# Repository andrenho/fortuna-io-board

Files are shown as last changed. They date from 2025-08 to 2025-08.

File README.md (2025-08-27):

# Fortuna IO board

**Fortuna I/O board** is a board that provides multiple I/O ports, and can be used to build a custom computer.

Board
VGA

The board main component is a [Raspberry Pi Pico 2 W](https://www.raspberrypi.com/products/raspberry-pi-pico-2/), which
has 2 processor cores. The 2nd core is used for managing the board I/O, leaving the 1st board available for whatever
the user decides to implement.

The board and accompanying firmware library provides:

 - 1 Raspberry Pi Pico 2 W core available for user implementation (3.8 MB flash and 350 kB RAM free)
 - USB power with on/off switch
 - VGA output at 640x480, 640x240 or 320x240 in 16 colors
 - special VGA mode at 320x240 with a background framebuffer + sprites (mode 4)
 - VGA text with 4 different fonts
 - support for USB keyboard
 - SD Card storage (using the libraries and [no-OS-FatFS-SD-SDIO-SPI-RPi-Pico](https://github.com/carlk3/no-OS-FatFS-SD-SDIO-SPI-RPi-Pico) and [FatFs](https://elm-chan.org/fsw/ff/))
 - Real Time (calendar) clock with long term storage, battery operated (CR2032)
 - UART interface (can be used with a FTDI cable)
 - audio output via headphone jack
 - user panel composed of two leds, one pushbutton and 2x microswitch
 - an external SPI interface (via a 5x2 pin IDC connector), allowing the board to be controller externally
 - Wi-Fi and Bluetooth via Pico Pi 2 W

## Schematic

Schematic

Possible variations:
 * Any of these modules, except for the Pico Pi 2 and the Power, are optional.
 * A Pico Pi (not W) can be used instead, if wireless is not needed.

[Download PDF](schematic/pi-pico-vga.pdf)

## Using it in a project

Look at `firmware/io-board/CMakeLists.txt` and `firmware/io-board/demo.c` for an example on how to import and use the library.

## Building the demo

To build the demo:

```shell
mkdir -p firmware/io-board/build
cd firmware/io-board/build
cmake -DPICO_SDK_PATH=~/pico-sdk -DPICOTOOL_FETCH_FROM_GIT_PATH=~/picotool -DPICO_BOARD=pico2 ..   # replace with your directories
make
```

# Emulator

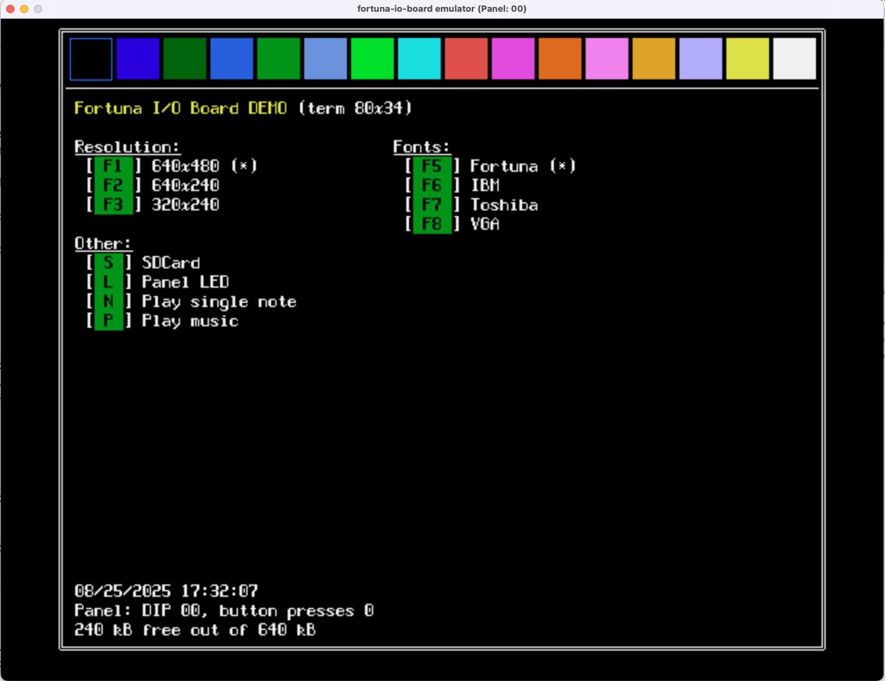
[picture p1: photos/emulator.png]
Emulator


An emulator can be used to test the implementation without having to upload it to the board. To build the emulator:

```shell
mkdir -p emulator/build
cd emulator/build
cmake ..
make
```

The same code that is uploaded to the board can also be used to compile the emulator. Look at `emulator/io-board/demo.c`,
which is just a link to the firmware implementation.

To create a disk image to use in the emulator, use the script `/tools/sdcard/create_image.sh`. To manage the disk image
(copy files to it, etc), the disk image needs to be mounted. In Linux, do 
`mount -o loop MY_IMAGE MOUNT_POINT`; in Mac, do `hdiutil attach MY_IMAGE` and access it through Finder.

(Macs needs to have `dosfstools` installed to use the `create_image.sh` script)

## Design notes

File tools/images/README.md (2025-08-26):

`imagegen.py` will generate an image that can be loaded on the Fortuna I/O Board. To create an image, follow this
procedure.

1. Create the image using the `fortuna.pal` palette file (recommended application: Grafx2)
2. Save image as PNG
3. Call `imagegen.py` to convert the PNG image into a Fortuna image

The image format is as this:

F0 34 -- magic number
01    -- image version (determines also compression type)
xx    -- transparent color (or FF for no transparency)
xx xx -- image width, in pixels
xx xx -- image height, in pixels
..... -- the image pixels (2 pixels per byte)

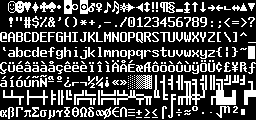
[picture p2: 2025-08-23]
tools/fonts/toshiba.png

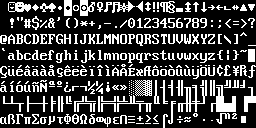
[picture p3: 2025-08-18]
tools/fonts/vga.png

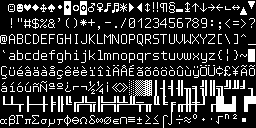
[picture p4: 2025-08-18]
tools/fonts/ibm.png

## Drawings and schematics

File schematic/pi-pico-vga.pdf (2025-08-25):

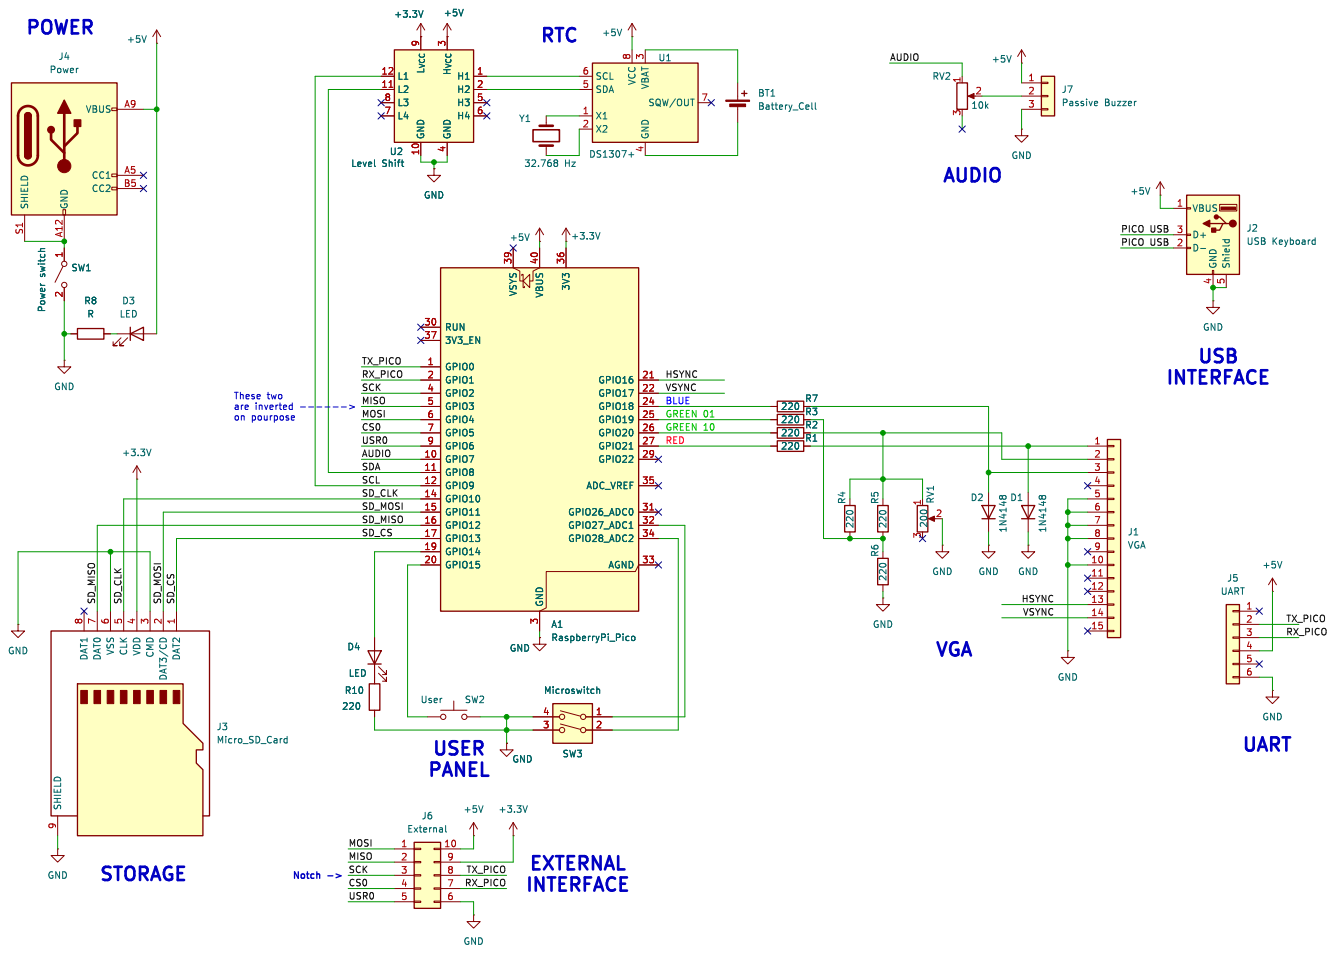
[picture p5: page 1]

4 SQW/OUT 7 U1 DS1307+ GND GND GND GND

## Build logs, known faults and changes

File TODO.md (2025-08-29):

## Version 2.0 - concurrent C version and emulator

- [x] Base (as library)
  - [x] Example implementation 
- [x] VGA framebuffer
  - [x] Framebuffer primitives
- [x] Framebuffer primitives and text
  - [x] Text tools
- [x] Keyboard / mouse / joystick
  - [x] Mouse pointer
- [x] Terminal
  - [x] Location in screen
  - [x] Cursor
  - [x] Colors
  - [x] Other fonts
- [x] Write program
  - [x] Translate HID
- [x] Change resolution
- [x] Memory available
- [x] Bug: font seems to be using RAM
- [x] SD card
- [x] Front panel
- [x] Real-time clock (get/set)
- [x] Audio
  - [x] Fix audio in board
- [x] Documentation

## Version 2.1

- [x] VGA
  - [x] Draw images
    - [x] Create palette and converter
    - [x] Transparency
- [x] Terminal
  - [x] Alternate character set
- [x] Emulator
  - [x] SDCard image file
- [x] Demo program: set clock
- [x] Dumb terminal mode with front panel settings
  - [x] Make it work on the emulator
  - [x] Single array for keys
  - [x] Add special keys
  - [ ] Edit UART configuration, change font, etc (write configuration on startup)
  - [ ] Respond with columns/lines size (and terminal type?)
  - [ ] Make terminal faster by caching fonts
  - [ ] Bell
  - [ ] Make advanced stuff work
    - [ ] vim
    - [ ] mc
    - [ ] nethack
  - [ ] Terminal connection not working very well on linux
- [ ] Update README.md, documentation

## Version 2.2

- [ ] Design communication language
- [ ] External connections
  - [ ] SPI
  - [ ] 4-pin
  - [ ] emulator

## Version 2.3

- [ ] Sprites
- [ ] Improve audio system
- [ ] Compressed images
- [ ] Merge master

## Version 2.4
- [ ] Create WASM version, auto-generate WASM page

--------------------------------------------

## Version 0.1

- [x] VGA simple framebuffer (640x480)
  - [x] Remove excess code
  - [x] Draw single pixel
- [x] Font generator
  - [x] Application to generate font to .h
- [x] Text framebuffer + color
  - [x] Draw characters
  - [x] Framebuffer
  - [x] Use callbacks to blink cursor
  - [x] Many chars
  - [x] Deal with ENTER
  - [x] Line feed
- [x] Better font (deal with multiple fonts)
- [x] Schematic

## Version 0.2

- [x] USB keyboard
- [x] Add version number
- [x] Add copyright
- [x] Test application
  - [x] cls
  - [x] bug with set_cursor
  - [x] longtext
  - [x] font
- [x] Finalize font
  - [x] boxes

## Version 0.3

- [x] SD Card
- [x] UART
- [x] Extra button / LED
- [x] Real-time clock + battery

## Version 0.4

- [x] Transform in library
- [x] Extra SPI port
- [x] Create examples
  - [x] Demo

## Version 1.0

- [x] Audio (?)
  - [x] All notes
- [x] WiFi/Bluetooth
- [x] Write documentation / rename

## Version 2.0

- [x] Configurable initialization
- [x] General code review
- [x] Print total RAM usage
- [x] User panel
  - [x] Detect changes to dipswitch
- [x] VGA improvements
  - [x] Text mode
    - [x] Don't use text backend (less memory)
    - [x] 4 different fonts

## Version 2.1

- [x] VGA mode 2 at lower resolution (320x240)
  - [x] 640x240 mode
  - [x] Tiles and sprites
  - [x] Drawing primitives
    - [x] Draw pixel
    - [x] Draw line
    - [x] Draw rectangle (line/filled)
    - [x] Draw ellipsis (line/filled)
    - [x] Fill area
    - [x] Draw image (with/without transparency)
    - [x] Draw character / text
  - [x] Customizable fonts
- [ ] USB
  - [x] Mouse
    - [x] Pointer
- [ ] Faster memcpy

# Version 2.2

- [ ] Terminal
  - [ ] Terminal via UART
- [ ] Automatic protocol
  - [ ] SPI
  - [ ] 4-bit
- [ ] Emulator (?)

## Version 2.3

- [ ] Advanced audio
  - [ ] Multiple channels (?)
  - [ ] Samples using PIO (?)
  - [ ] Noise
- [ ] Joystick
- [ ] Conditional compilation
- [ ] Github actions - generate uf2

## Version 2.3

- [ ] Revamp demo mode - create operating system-like
- [ ] Add development tools
  - [ ] Demo program
    - [ ] Wi-Fi
  - [ ] Pixelart tool
  - [ ] Sound editor

# Ideas for version 2

- Overclock
- 8-bit VGA
  - Mode 1: 640x480 - 16 colors
  - Mode 2: 320x240 - 256 colors + sprites
- 2nd Pi Pico just for audio
  - load samples from SDCard

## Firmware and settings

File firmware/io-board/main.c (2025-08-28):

#include "fortuna.h"

extern void demo();
extern void terminal();

int main(int argc, char* argv[])
{
    fortuna_init(DEFAULT_QUEUE_SIZE, NULL, argc, argv);

    // fixating points (used to calibrate the monitor)
    fb_set_pixel(vga_framebuffer(), 0, 0, C_NAVY_BLUE);
    fb_set_pixel(vga_framebuffer(), 0, vga_height() - 1, C_NAVY_BLUE);
    fb_set_pixel(vga_framebuffer(), vga_width() - 1, 0, C_NAVY_BLUE);
    fb_set_pixel(vga_framebuffer(), vga_width() - 1, vga_height() - 1, C_NAVY_BLUE);

    switch (panel_get_dipswitch()) {
        case 0b00:
            demo();
        case 0b01:
            terminal();
        default:
            terminal_start(fb_default_font());
            terminal_write("DIP switch configuration not supported.");
            for (;;);
    }
}

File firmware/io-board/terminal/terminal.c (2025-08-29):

#include "fortuna.h"

#include <pico.h>
#include <pico/util/queue.h>
#include <contrib/libtmt/tmt.h>

// https://gist.github.com/ConnerWill/d4b6c776b509add763e17f9f113fd25b
// https://claude.ai/public/artifacts/8b851796-06be-455c-8535-2e74ab6023db

#define MAX_QUEUE_SIZE (16 * 1024)
static queue_t ch_queue;

typedef struct {
    uint8_t     hid;
    const char* str;
} HidString;

static const HidString __in_flash() hid_strings[] = {
    { HID_KEY_ARROW_UP,    TMT_KEY_UP },
    { HID_KEY_ARROW_DOWN,  TMT_KEY_DOWN },
    { HID_KEY_ARROW_RIGHT, TMT_KEY_RIGHT },
    { HID_KEY_ARROW_LEFT,  TMT_KEY_LEFT },
    { HID_KEY_HOME,        TMT_KEY_HOME },
    { HID_KEY_END,         "\e[F" },
    { HID_KEY_INSERT,      TMT_KEY_INSERT },
    { HID_KEY_BACKSPACE,   TMT_KEY_BACKSPACE },
    { HID_KEY_TAB,         "\t" },
    { HID_KEY_PAGE_UP,     TMT_KEY_PAGE_UP },
    { HID_KEY_PAGE_DOWN,   TMT_KEY_PAGE_DOWN },
    { HID_KEY_F1,          TMT_KEY_F1 },
    { HID_KEY_F2,          TMT_KEY_F2 },
    { HID_KEY_F3,          TMT_KEY_F3 },
    { HID_KEY_F4,          TMT_KEY_F4 },
    { HID_KEY_F5,          TMT_KEY_F5 },
    { HID_KEY_F6,          TMT_KEY_F6 },
    { HID_KEY_F7,          TMT_KEY_F7 },
    { HID_KEY_F8,          TMT_KEY_F8 },
    { HID_KEY_F9,          TMT_KEY_F9 },
    { HID_KEY_F10,         TMT_KEY_F10 },
    { HID_KEY_F11,         "\e[23~" },
    { HID_KEY_F12,         "\e[24~" },
    { HID_KEY_ESCAPE,      "\e" },
};

static const HidString __in_flash() hid_strings_ctrl[] = {
    { HID_KEY_ARROW_UP,    "\e[1;5A" },
    { HID_KEY_ARROW_DOWN,  "\e[1;5B" },
    { HID_KEY_ARROW_RIGHT, "\e[1;5C" },
    { HID_KEY_ARROW_LEFT,  "\e[1;5D" },
    { HID_KEY_HOME,        "\e[1;5H" },
    { HID_KEY_END,         "\e[1;5F" },
    { HID_KEY_INSERT,      "\e[2;5~" },
    { HID_KEY_BACKSPACE,   "\b" },
    { HID_KEY_TAB,         "\t" },
    { HID_KEY_PAGE_UP,     "\e[5;5~" },
    { HID_KEY_PAGE_DOWN,   "\e[6;5~" },
    { HID_KEY_F1,          "\e[1;5P" },
    { HID_KEY_F2,          "\e[1;5Q" },
    { HID_KEY_F3,          "\e[1;5R" },
    { HID_KEY_F4,          "\e[1;5S" },
    { HID_KEY_F5,          "\e[15;5~" },
    { HID_KEY_F6,          "\e[17;5~" },
    { HID_KEY_F7,          "\e[18;5~" },
    { HID_KEY_F8,          "\e[19;5~" },
    { HID_KEY_F9,          "\e[20;5~" },
    { HID_KEY_F10,         "\e[21;5~" },
    { HID_KEY_F11,         "\e[23;5~" },
    { HID_KEY_F12,         "\e[24;5~" },
    { HID_KEY_ESCAPE,      "\e" },
};

static const HidString __in_flash() hid_strings_shift[] = {
    { HID_KEY_ARROW_UP,    "\e[1;2A" },
    { HID_KEY_ARROW_DOWN,  "\e[1;2B" },
    { HID_KEY_ARROW_RIGHT, "\e[1;2C" },
    { HID_KEY_ARROW_LEFT,  "\e[1;2D" },
    { HID_KEY_HOME,        "\e[1;2H" },
    { HID_KEY_END,         "\e[1;2F" },
    { HID_KEY_INSERT,      "\e[2;5~" },  // TODO
    { HID_KEY_BACKSPACE,   "\x7f" },
    { HID_KEY_TAB,         "\e[Z" },
    { HID_KEY_PAGE_UP,     TMT_KEY_PAGE_UP },  // TODO
    { HID_KEY_PAGE_DOWN,   TMT_KEY_PAGE_DOWN },
    { HID_KEY_F1,          "\e[1;2P" },
    { HID_KEY_F2,          "\e[1;2Q" },
    { HID_KEY_F3,          "\e[1;2R" },
    { HID_KEY_F4,          "\e[1;2S" },
    { HID_KEY_F5,          "\e[15;2~" },
    { HID_KEY_F6,          "\e[17;2~" },
    { HID_KEY_F7,          "\e[18;2~" },
    { HID_KEY_F8,          "\e[19;2~" },
    { HID_KEY_F9,          "\e[20;2~" },
    { HID_KEY_F10,         "\e[21;2~" },
    { HID_KEY_F11,         "\e[23;2~" },
    { HID_KEY_F12,         "\e[24;2~" },
    { HID_KEY_ESCAPE,      "\e" },
};


static const HidString __in_flash() hid_strings_ctrl_shift[] = {
    { HID_KEY_ARROW_UP,    "\e[1;6A" },
    { HID_KEY_ARROW_DOWN,  "\e[1;6B" },
    { HID_KEY_ARROW_RIGHT, "\e[1;6C" },
    { HID_KEY_ARROW_LEFT,  "\e[1;6D" },
    { HID_KEY_HOME,        "\e[1;6H" },
    { HID_KEY_END,         "\e[1;6F" },
    { HID_KEY_INSERT,      "\e[2;6~" },
    { HID_KEY_BACKSPACE,   "\b" },
    { HID_KEY_TAB,         "\t" },
    { HID_KEY_PAGE_UP,     "\e[5;6~" },
    { HID_KEY_PAGE_DOWN,   "\e[6;6~" },
    { HID_KEY_F1,          "\e[1;6P" },
    { HID_KEY_F2,          "\e[1;6Q" },
    { HID_KEY_F3,          "\e[1;6R" },
    { HID_KEY_F4,          "\e[1;6S" },
    { HID_KEY_F5,          "\e[15;6~" },
    { HID_KEY_F6,          "\e[17;6~" },
    { HID_KEY_F7,          "\e[18;6~" },
    { HID_KEY_F8,          "\e[19;6~" },
    { HID_KEY_F9,          "\e[20;6~" },
    { HID_KEY_F10,         "\e[21;6~" },
    { HID_KEY_F11,         "\e[23;6~" },
    { HID_KEY_F12,         "\e[24;6~" },
    { HID_KEY_ESCAPE,      "\e" },
};


static void on_uart_rx()
{
    while (uart_is_readable(uart0)) {
        char ch = uart_getc(uart0);
        if (ch == 0)
            break;
        queue_try_add(&ch_queue, &ch);
    }
}
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
